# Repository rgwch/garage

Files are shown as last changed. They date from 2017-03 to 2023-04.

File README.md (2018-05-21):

# garage

Garagentoröffner per Raspberry Pi mit Relaisausgang und NodeJS-Express Server.
Der Server lässt sich per WebApp bedienen. Der Zustand des Tors (offen/zu) wird mit
einem Ultraschall-Sensor bestimmt. Wenn das Tor offen ist, wird ein weiterer Entfernungsmesser
eingeschaltet, der als Abstandswarner an der Stirnseite dient.

## Hardware

* Raspberry Pi Zero, B+, 2 oder 3.
* 2 Relais oder Optokoppler
* 2 HC-SR-04 oder HC-SR-05 Ultraschall-Sensoren
* 1 Arduino Nano
* 3 Leuchtdioden grün / gelb / rot für Abstandswarner
* 2 Widerstände 330 Ohm
* 1 Widerstand 470 Ohm
* 1 Netzteil für Raspberry Pi (Der Arduino wird über den Raspberry versorgt)

3D-Drucker für die Gehäuse.

## Software

NodeJS 10.x, z.B. so:

      sudo apt-get remove nodejs
      cd
      mkdir apps
      cd apps
      wget http://nodejs.org/dist/latest-v10.x/node-v10.1.0-linux-armv6l.tar.xz
      tar -xf node-v10.1.0-linux-armv6l.tar.xz
      mv node-v10.1.0-linux-armv6l node10
      sudo ln -s /home/pi/apps/node10/bin/node /usr/bin/node
      sudo ln -s /home/pi/apps/node10/bin/npm /usr/bin/npm
      echo export PATH=$PATH:/home/pi/apps/node10/bin >>../.profile

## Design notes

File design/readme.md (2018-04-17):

# Design Dateien

## *.scad

Dies sind Programme im OpenScad-Format, 
um die Gehäuse für den Raspberry, den Arduino und die Sensoren zu drucken.

Vorgehen, zum Beispiel für Ubuntu 17.04:

* `sudo apt-get install openscad slic3r`
* slic3r starten und Default-Einstellungen passend zum 3D-Drucker einstellen. (Vor allem Druckbett-Grösse, Filament-Durchmesser, Heizung)
* `./build_all.sh`
* gcode Dateien zum Drucker schicken.

### Dateien

* hc-sr04.scad / png: Gehäuse für den Ultraschallsensor des Garentor-Öffners
* klammer.scad / png: Klammer, um den Sensor an der Schiene des Tors zu befestigen
* nano_sono.scad / png: Gehäuse für Ultraschallsensor, Arduino und LEDs des Abstanswarner
* garage.fzz / png: Schema des Elektronik Aufbaus (Frtitzing Format)

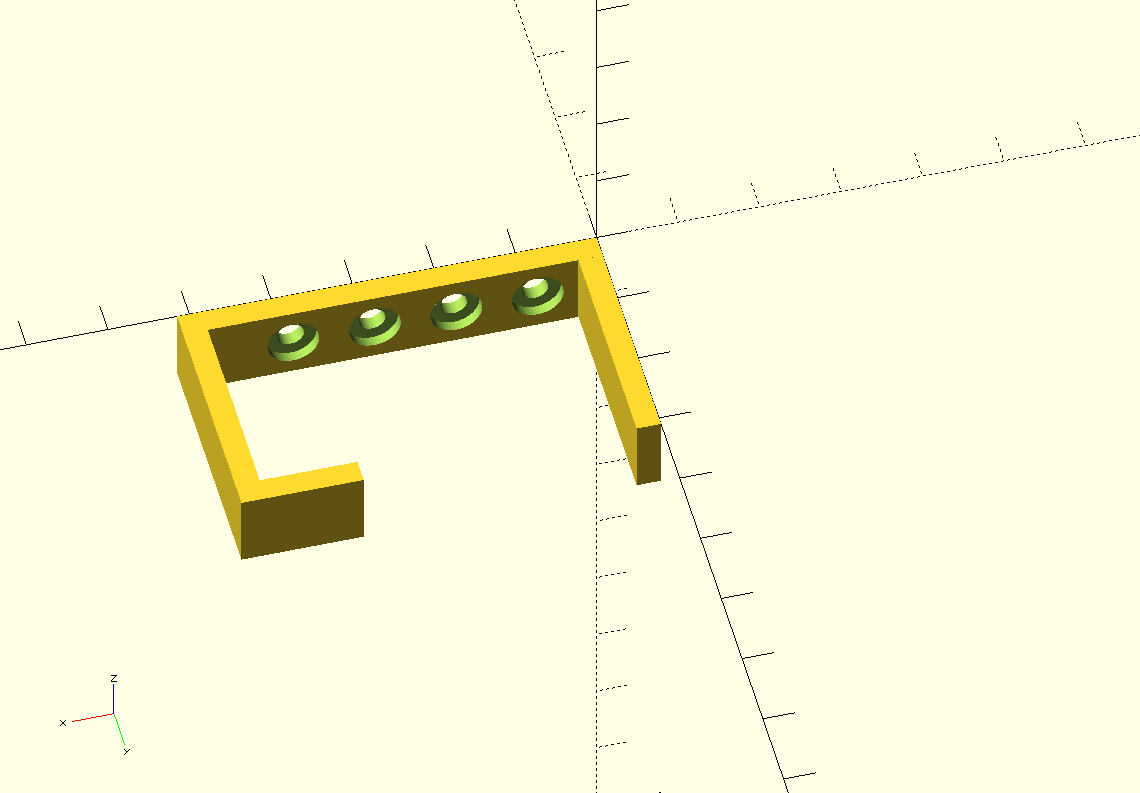
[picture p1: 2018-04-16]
design/klammer.png

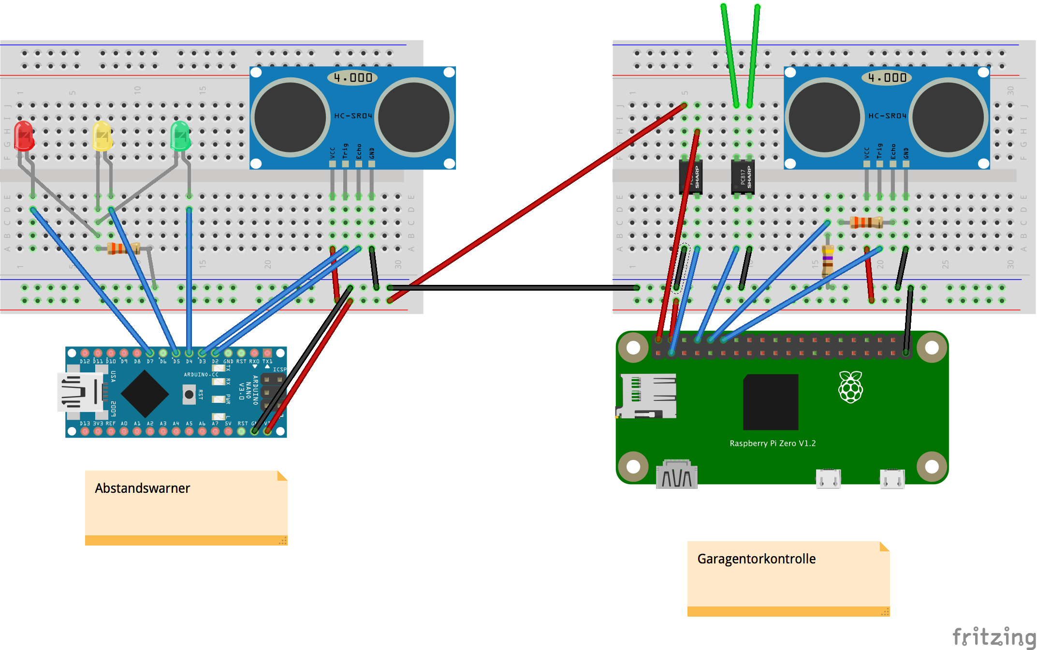
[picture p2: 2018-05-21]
design/garage_bb.png

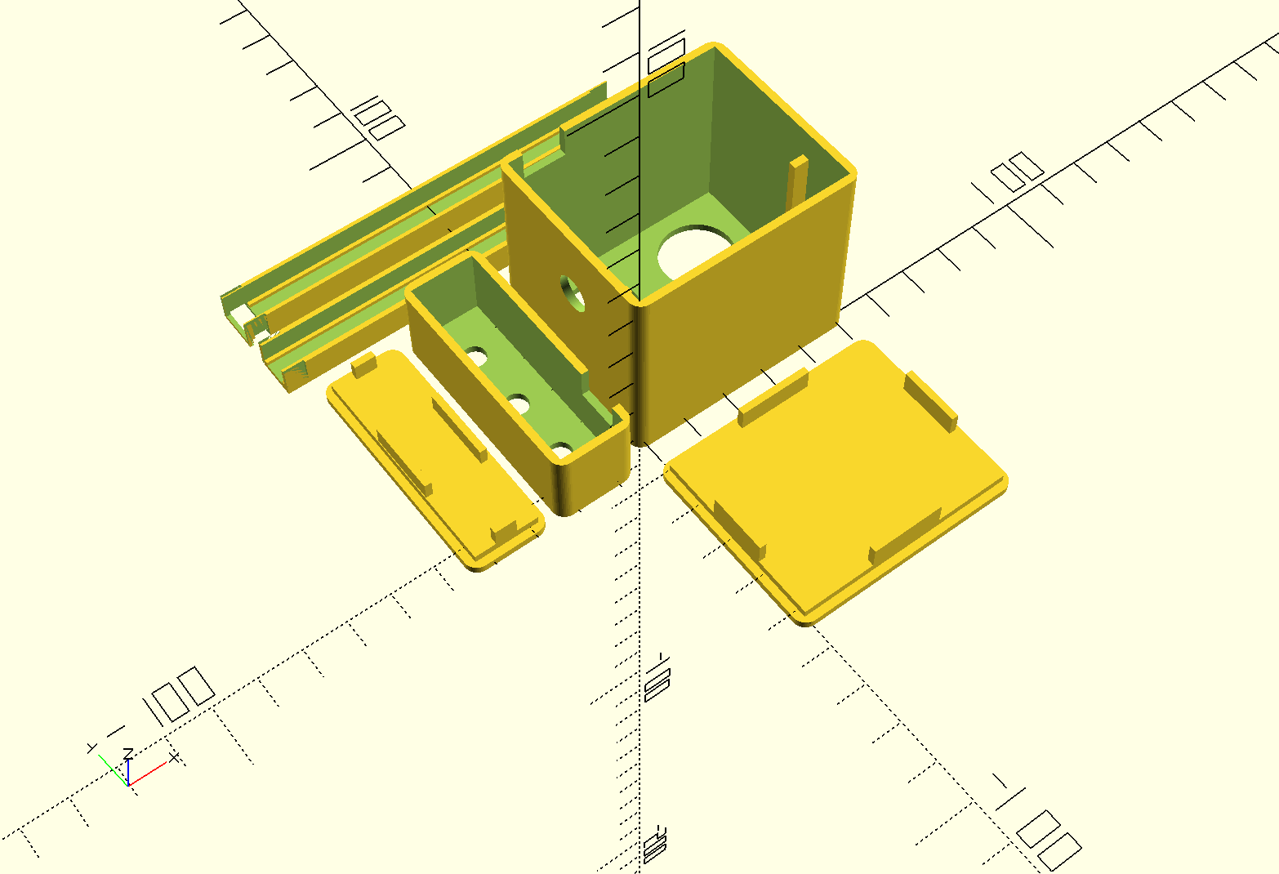
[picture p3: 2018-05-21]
design/nano_sono_v3.png

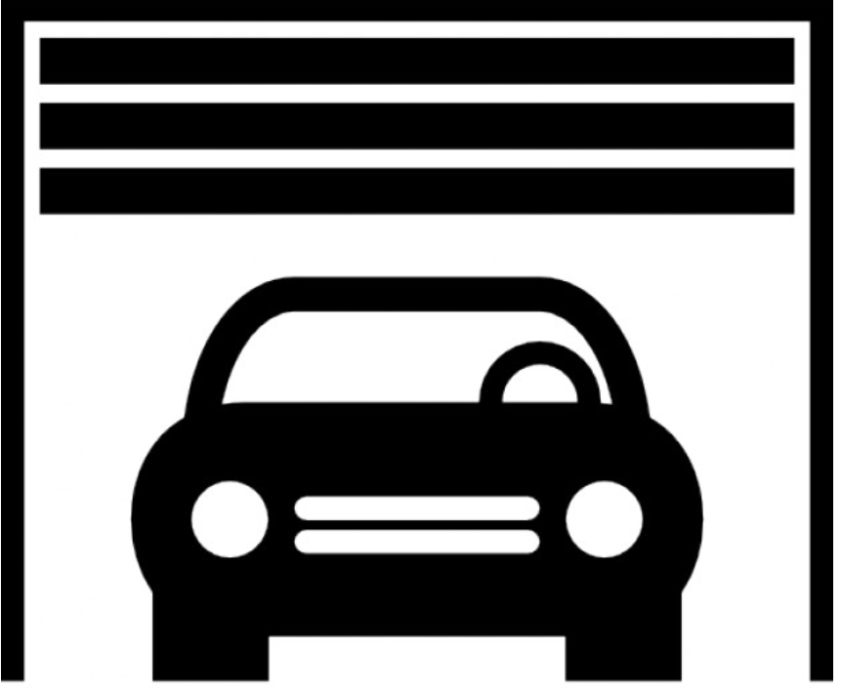
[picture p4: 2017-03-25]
public/garage.png

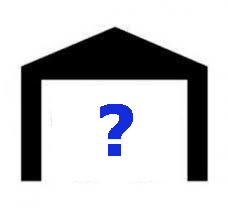
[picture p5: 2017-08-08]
public/garage_frage.png

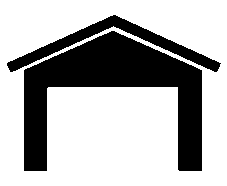
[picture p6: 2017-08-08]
public/garage_closing.gif

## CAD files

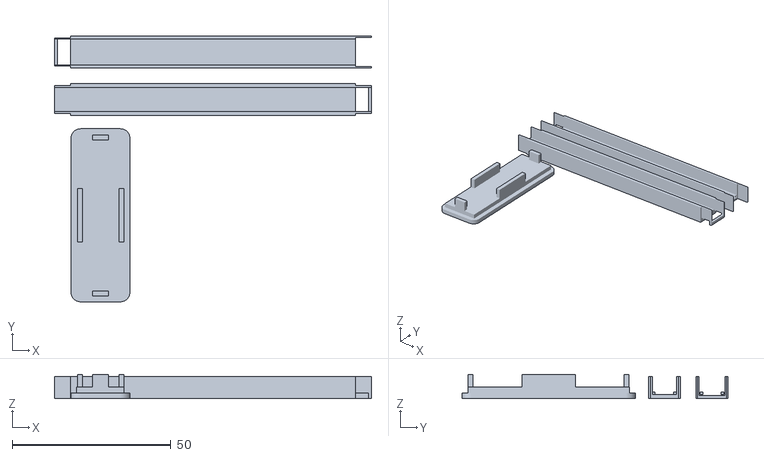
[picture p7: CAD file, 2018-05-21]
design/nano_sono_v3.stl
100.0 x 83.8 x 7.60

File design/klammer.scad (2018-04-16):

fit=0.2;
width=10;
thick=3;
inner_height=45.5;
inner_depth=25;
hook_size=12;
screw_head_diameter=6.0;
screw_head_thick=2.8;
screw_diameter=2.9;
screw_head_round=true;

height=inner_height+2*thick;
depth=inner_depth+2*thick;

front=[width,thick,inner_height];
top=[width,inner_depth,thick];
hook=[width,thick,hook_size];
fill=[width,thick,thick];

rotate([0,90,0]){
    union(){
        translate([0,0,thick]){
            difference(){
                cube(front);
                screw(5);
                screw(15);
                screw(25);
                screw(35);
            }
            translate([0,thick,inner_height]){
                cube(top);
                translate([0,top.y,-hook_size])
                    cube(hook);
            }
            translate([0,thick,-thick]){
                cube(top);
            }
        }

        translate([0,0,0]) cube(fill);
        translate([0,0,height-thick]) cube(fill);
        translate([0,depth-thick,0]) cube(fill);
        translate([0,depth-thick,height-thick]) cube(fill);
        
    }
}
module screw(pos){
    rotate([90,0,0]){
        translate([width/2,pos,-(1.5*thick)]){
            cylinder(r=screw_diameter/2+fit,h=thick*2,$fn=50);
            if(screw_head_round==false){
                cylinder(r=screw_head_diameter/2+fit,h=screw_head_thick,$fn=6);
            }else{
                cylinder(r=screw_head_diameter/2+fit,h=screw_head_thick,$fn=50);                 
            }
        }
    }
}

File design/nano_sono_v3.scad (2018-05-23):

/**********************************************************
    Gehäuse für einen HC-SR04 oder 05 Ultraschall Sensor, 
    einen Arduino Nano und 3 LEDs
    
    Schichtdicke: 0.3 mm, Filament PLA 1.75 mm
*********************************************************/
include <toolbox_1.1.scad>
use <devices.scad>

thick=1.8;              // Wanddicke. 
length=46;      // Platzbedarf für den HC-SR 04
width=21;
depth=17;
diameter=17;            // Durchmesser der Sender/Empfänger
offset=1.9;             // Abstand Sender/Empfänger von Wand
steps=100;              // Schritte für Kreisberechnung
platine_t=1.5;          // Masse der Platine mit dem Arduino
platine_w=38;
platine_l=48;
height=42;
clearance_floor=5;      // Abstand von der Unterseite für Verdrahtungen etc.
racksize=3.5;           // Grösse der Führungsschienen für die Platine
level_y=clearance_floor+thick+platine_t+racksize;
ledsize=5.35;            // Durchmesser der LEDs (inkl. Schrumpfkorrektur)
channel_width=10;
channel_depth=7;
channel_thick=1.2;      // Wandstärke Verbindungskanal

/*
    Die Box
*/

union(){
    difference(){
         roundedBox([platine_l,height,platine_w+5],3,thick);  
        translate([center(platine_l,length),height-diameter-3*offset,-offset])
            hcsr04();
        
        buchse(platine_w-15);
        translate([2*thick,height-5,platine_w])
           cube([10,10,7]);
    }

    rack([0,clearance_floor+thick,thick]);
    rack([platine_l-racksize,clearance_floor+thick+5,thick]); 
    translate([center(platine_l,10),19,0])
        cube([10,5,3]);
}


/*
    Der Deckel
*/


union(){
            translate([0,-(height+10),0]){
                roundedCover([platine_l,height,0],3,thick,latch_x=5,latch_y=5);
            }
     
}


/*
 Das abgesetzte Gehäuse für die LEDs
*/

union(){
   
    translate([-7,-4,0]){
      rotate([0,0,90])
        difference(){
            roundedBox([platine_l,15,15],3,thick);
            offs=3;    
            dist=(platine_l-2*offs)/3;    
            led(offs+dist/2);
            led(offs+dist+dist/2);
            led(offs+2*dist+dist/2);
            translate([2*thick,-5,10])
                cube([10,10,7]);
  
        }    
    }
}


/*
Deckel für LED Gehäuse
*/
translate([-28,-4,0]){
    rotate([0,0,90])
        roundedCover([platine_l,15,0],3,thick,latch_x=4,latch_y=4);
}

// Verbindungskanal 
translate([-50,platine_w+15,-thick]){
    union(){
    difference(){
            cube([100,channel_width,channel_depth]);
     
        translate([-5,channel_thick,channel_thick])
            cube([110,channel_width-2*channel_thick,channel_depth]);
        
        translate([95,0,0]) 
            cube([10,channel_thick/2,10]);
        translate([95,channel_width-channel_thick/2,0])
            cube([10,channel_thick/2,10]); 
        translate([95,-5,-2])
             cube([4,15,thick+2]);
        
        translate([0,0,0]) 
            cube([5,channel_thick/2,10]);
        translate([0,channel_width-channel_thick/2,0])
            cube([5,channel_thick/2,10]); 
     
        
    }
    translate([0,channel_thick,channel_thick]) cube([95,0.9,0.9]);
    translate([0,channel_width-0.9-channel_thick,channel_thick]) 
        cube([95,0.9,0.9]);
      
    }
}

translate([-50,platine_w+30,-thick]){
    union(){
     difference(){
        cube([100,channel_width,channel_depth]);
        translate([-5,channel_thick,channel_thick])
            cube([110,channel_width-2*channel_thick,channel_depth]);
         
        translate([95,channel_thick/2,0]) 
            cube([5,channel_thick/2,10]);
        translate([95,channel_width-channel_thick,0])
            cube([5,channel_thick/2,10]); 
         
        translate([95,channel_thick/2,-channel_thick])
            cube([5,channel_width-channel_thick,10]);
         cube([5,channel_thick/2,10]);
        translate([0,channel_width-channel_thick/2,0])
            cube([5,channel_thick/2,10]);
        translate([1,-5,-2])
          cube([4,15,thick+2]);
        
    }
    translate([5,channel_thick,channel_thick]) cube([90,0.9,0.9]);
    translate([5,channel_width-0.9-channel_thick,channel_thick]) 
        cube([90,0.9,0.9]);
    
    }
}


module led(x){
    translate([x,8,-thick-3])
        cylinder(r=ledsize/2,h=10,$fn=steps);           

}
    
module buchse(x){
    translate([-5,height/2.2,thick+4+x])
        rotate([0,90,0])
            cylinder(r=4.1,h=10,$fn=steps);
    
}

module rack(pos){
translate(pos) 
    cube([racksize,1.8,platine_w-thick]);

}

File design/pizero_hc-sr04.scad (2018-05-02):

/****************************************************************************************
    Gehöuse für einen Raspberry Pi Zero, einen HC-SR-04 oder HC-SR-05 Ultraschall-Sensor
    ein Relais und eine Steckbuchse.
    
    Material: PLA 1.75mm
    Schichtdicke: 0.3mm
    Infill: 20%
    Support: Nein
****************************************************************************************/
include  <toolbox_1.1.scad>

// Wanddicke global 
thick=1.2;

// Stufenzahl für runde Strukturen
steps=100;

// Raspberry-Teil
base_length=65.4;   // Länge der Platine
spare_length=3;     // Reserve Länge
base_width=30;      // Breite der Platine
spare_width=2;      // Reserve Breite
corner_radius=3;    // Rundungsradius (nur wenn roundedBox als Basis genommen wird)
hole_offset=3.5;    // Abstand der Löcher von den Kanten
raspi_height=15;    // Höhe für die Raspi Platine inkl. Anschlüsse
hc05_height=23;     // Höhe für den Ulztraschall-Sensor
total_height=raspi_height+hc05_height;
support_radius=3.5; // Radius der Stützscheiben
support_height=2;   // Dicker der Stptzscheiben, Bodenfreiheit für den Raspi
pillar_radius=2.5/2;    // Dicke der Löcher
pillar_height=4;    // Höhe der Führungsstifte für die RAspi-Halterung

// HC-SR-05 Teil
hc05_length=46; 
hc05_width=21;
hc05_depth=17;
hc05_diameter=17;
hc05_offset=1.9;
 
// Halterungen 
screw=3;            // Dicke der Schraube
fixation_size=8;   // Dicke der Halter
fixation_depth=8;
  


// Raspberry
union(){
    difference(){
        box(inner_size=[base_length+2*spare_length,base_width+2*spare_width,raspi_height+hc05_height],radius=corner_radius,thick=thick);
        
    // Stromanschluss    
    translate([spare_length+49.5,-5-thick,support_height+1])    
        cube([10,10,5]);  
    // Kühlschlitze im Boden    
    for(i=[10:5:45])  slot(i,base_width);  

    // Öffnungen für Ultraschall-Sensor
    rotate([90,0,0]){
        translate([
            hc05_diameter/2+hc05_offset,
            hc05_diameter/2+raspi_height+hc05_offset,
            -thick])
                cylinder(r=hc05_diameter/2,h=hc05_depth+5,$fn=steps);
        
        
        translate([hc05_length-hc05_diameter/2-hc05_offset,
               hc05_diameter/2+raspi_height+hc05_offset,
                -thick])
                cylinder(r=hc05_diameter/2,h=hc05_depth+5,$fn=steps);
        }
    // Öffnung für Steckbuchse
        rotate([90,0,90]){
            translate([base_width-23,raspi_height+10,base_length])
                cylinder(r=4.1,h=10,$fn=steps);
        
            }
        translate([base_length+spare_length,15,raspi_height+1.5])
               cube([10,17.2,14.3]);
    }
    
    
    // Stützen
    raspi_pillar(spare_length+hole_offset+0.3,spare_width+hole_offset);
    raspi_pillar(spare_length+base_length-hole_offset,spare_width+hole_offset);
    raspi_pillar(spare_length+hole_offset+0.3,base_width+spare_width-hole_offset);
    raspi_pillar(spare_length+base_length-hole_offset,base_width+spare_width-hole_offset);
    
    inlay_pillar(0,0);
    inlay_pillar(0,base_width+2*spare_width-2);
    inlay_pillar(base_length+2*spare_length-2,0);
    inlay_pillar(base_length+2*spare_length-2,base_width+2*spare_width-2);
    
    translate([-fixation_size,
        base_width+fixation_size/2+thick,
        -thick]) fixation();
    translate([base_length+2*spare_length,
        base_width+fixation_size/2+thick,
        -thick]) fixation();
}

// Zwischenboden
translate([0,-base_width-spare_width-4,-thick])
        inlay();

// Deckel
translate([0,base_width+spare_width+2*thick+3]){
    difference(){
        cover(inner_size=[base_length+2*spare_length,base_width+2*spare_width,raspi_height+     hc05_height], thick=thick, latch_y=5, latch_x=2);
     for(i=[4:5:54]) slot(i,base_width);   
        
   }
}


// Träger mit Führungsstift für den Raspi
module raspi_pillar(x,y){
    translate([x,y,0]){
        union(){
            cylinder(r=support_radius,h=support_height,$fn=steps);
            cylinder(r=pillar_radius,h=pillar_height,$fn=steps);
        }
    }
    
}

// Stütze für Zwischenboden
module inlay_pillar(x,y){
    translate([x,y,0]) 
        cube([2,2,raspi_height-2]);
}

// Zwischenboden
module inlay(){
    difference(){
        cube([base_length+2*spare_length-0.6,base_width+2*spare_width-0.3,1.5]);
      translate([5,2,-thick-4])
        cube([35,19,thick+10]);
      translate([5,24.5,thick-4])
        cube([base_length-5,12,thick+10]);
  
    }
    
}

// Halterung mit Öffnung für M3 Schraube
module fixation(x){
    difference(){
        rotate([90,0,0])
        roundedCube([fixation_size,fixation_depth,fixation_size],radius=3);
            rotate([90,0,0])
                translate([fixation_size/2,fixation_depth/2,-30])
                    cylinder(d=screw,h=50,$fn=steps);
    }
}

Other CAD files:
design/relay.scad
design/toolbox.scad
design/toolbox_1.1.scad

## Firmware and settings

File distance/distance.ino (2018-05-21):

/**
 * Sketch für Arduino:
 * Entfernung messen, und je nachdem eine rote, gelbe oder grüne LED einschalten
 */
 // Pins definieren
const int trigger = 5;
const int echo = 6;
const int red=7;
const int yellow=8;
const int green=9;

const int RED_DISTANCE=15; //cm
const int YELLOW_DISTANCE=50;

const long MAX_TIME = 20000;

void setup() {
  pinMode(trigger,OUTPUT);
  pinMode(echo,INPUT);
  pinMode(red,OUTPUT);
  pinMode(yellow,OUTPUT);
  pinMode(green,OUTPUT);
}

// Alle 500ms eine Messung machen und LEDs entsprechend schalten.
// Delays für Blinkeffekt
void loop() {
  digitalWrite(red,0);
  digitalWrite(yellow,0);
  digitalWrite(green,0);
  delay(250);
  int distance=ping();
  if(distance<RED_DISTANCE){
    digitalWrite(red,1);
  }else if(distance<YELLOW_DISTANCE){
    digitalWrite(yellow,1);
  }else{
    digitalWrite(green,1);
  }
  delay(250);
}

/*
  Der HC-SR04 startet eine Messung mit fallender Flanke auf trigger, auf dem vorher mindestens
  10us HIGH angelegt war. Er setzt dann echo zunächst auf HIGH und bei Empfang des Echos wieder auf LOW.

  Entfernung messen: trigger auf LOW, dann 15 us auf HIGH,
  dann wieder auf LOW, dann darauf warten, dass der Echo-Pin von HIGH auf LOW geht 
  und aus der dazwischen liegenden Zeit die 
  Entfernung berechnen (Schallgeschwindigkeit in Luft: 0.034cm/us).
*/
int ping() {
  digitalWrite(trigger,LOW);
  delay(2);
  digitalWrite(trigger, HIGH);
  delayMicroseconds(15);
  digitalWrite(trigger, LOW);
  long time = pulseIn(echo, HIGH);
  return (time/2)*0.034;
}

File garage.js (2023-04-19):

/**
 *  Garagentor-Fernbedienung mit Raspberry Pi
 *  (c) 2017-2018 by G. Weirich
 *
 * 8.4.2018: Verwende Ultraschall Sensor HC SR 04 zum feststellen, wo das Garagentor steht anstelle des
 * Mikroschalters. Damit wird das Problem behoben, dass die Anzeige unzuverlässig ist, weil das Garagentor
 * nicht immer exakt am selben Ort anhält (abhängig von Temperatur, Luftfeuchtigkeit, Gespenstern usw.)
 * Wir vereinfachen das: Wenn die Oberkante des Garagentors näher als MAX_DISTANCE vom Sensor ist,
 * betrachten wir es als offen.
 * 15.4.2018: Wechsel vom PiFace auf ein Standard-Relais, das mit onoff geschaltet wird.
 * Ausserdem neue Funktion: Abstandswarner an der Stirnseite der Garage einschalten, wenn das Tor offen ist.
 */

/* eslint-disable no-console*/
'use strict'

// Damit wir das Programm auf einem normalen PC ohne GPIO testen können. Wenn es auf dem echten Pi läuft, true setzen
const realpi = false
//const debug = false;

// Pin-Definitionen
const GPIO_GARAGE = 18 // Relais für Garagentorantrieb
const GPIO_ECHO = 15 // Echo vom HC-SR-04
const GPIO_TRIGGER = 14 // Trigger für den HC-SR-04

// Welcher Pin-Zustand den Aktor einschaltet. Hängt vom verwendeten Relais-Typ ab
const ON = 0
const OFF = 1

// Maximaldistanz, bis zu der das Garagentor als offen erkannt wird.
const MAX_DISTANCE = 100

// Dauer des simulierten Tastendrucks in Millisekunden
const time_to_push = 800
// Dauer des Öffnungs/Schliessvorgangs des Tors in ms
const time_to_run = 17000
// Aussperren bei falscher Passworteingabe in ms
const lock_time = 3000

const checkLightState = 'http://homepi.lan:8087/get/aussenlicht_manuell'
const setLightState = 'http://homepi.lan:8087/set/aussenlicht_manuell?value='

const fs = require('fs')
const ping = require('./measure')
const fetch = require('node-fetch')
const https = realpi ? require('https') : require('http')
const express = require('express')
const nconf = require('nconf')
const hash = require('crypto-js/sha256')
const path = require('path')
const bodyParser = require('body-parser')
const salt = "um Hackern mit 'rainbow tables' die Suppe zu versalzen"
const favicon = require('serve-favicon')

nconf.file(__dirname + '/users.json')
const app = express()
// Dieses Flag nutzen wir später, um den Server temporär inaktiv zu schalten.
let disabled = false
// Dieses Flag zeigt an, dass das Garagentor gerade fährt
let running = false
// Hier sammeln wir schiefgegangene Login-Versuche
const failures = {}

app.set('view-cache', true)
app.use(favicon(path.join(__dirname, 'public', 'favicon.ico')))
app.use(express.static(path.join(__dirname, 'public')))

/*
 HTTPS-Server erstellen, damit Usernamen und Passwörter verschlüsselt übermittelt werden.
 Als Zertifikat kann man entweder ein self-signed certificate verwenden
 (openssl req -x509 -newkey rsa:2048 -keyout key.pem -out cert.pem -days 365 -nodes).
 Dann muss man allerdings damit leben, dass der Browser eine "Sicherheitswarnung" ausgibt.

 Oder man erstellt ein Zertifikat via letsencrypt, mit "sudo certbot certonly --manual" und kopiert
 "privkey.pem" nach "key.pem" und "fullchain.pem" nach "cert.pem".
 Dann muss man allerdings, das Zertifikat alle drei Monate erneuern, weil Letsencrypt keine länger gültigen
 Zertifikate ausstellt.

 Oder man kauft irgendwo ein kostenpflichtiges Zertifikat. Aber das scheint mir für einen Garagentorantrieb
 eigentlich zu aufwändig.

 Wenn realpi==false ist, wird ein http-server ohne ssl gestartet.
 */

let src = __dirname
https
  .createServer(
    {
      key: realpi ? fs.readFileSync(src + '/key.pem') : '',
      cert: realpi ? fs.readFileSync(src + '/cert.pem') : '',
    },
    app,
  )
  .listen(2017)

// Auf einem echten Pi ist Gpio auf onoff (https://www.npmjs.com/package/onoff) gesetzt
// Auf einem anderen PC wird es einfach mit leeren Funktionen simuliert.

let relay
let hc_trigger
let hc_echo
let lightState

if (realpi) {
  const Gpio = require('onoff').Gpio

  relay = new Gpio(GPIO_GARAGE, 'high')
  hc_trigger = new Gpio(GPIO_TRIGGER, 'out')
  hc_echo = new Gpio(GPIO_ECHO, 'in')
} else {
  let Fake = require('./fakegpio')
  relay = new Fake(GPIO_GARAGE, 'out')
  hc_trigger = new Fake(GPIO_TRIGGER, 'out')
  hc_echo = new Fake(GPIO_ECHO, 'in')
}

relay.writeSync(OFF)

/**
 * Expressjs sagen, dass die Views im Verzeichnis "views" zu finden sind, und dass
 * pug (ex-Jade) benötigt wird, um sie nach HTML zu konvertieren.
 */
app.set('views', path.join(__dirname, 'views'))
app.set('view engine', 'pug')

/**
 * Expressjs mitteilen, dass wir json- und urlencoded Parameter im request body erwarten
 */
app.use(bodyParser.json())
app.use(
  bodyParser.urlencoded({
    extended: false,
  }),
)

/************************
 * Hilfsfunktionen
 *
 ************************/

/**
 * Password hashen
 * @param pwd Klartext-Passwort
 * @returns sha256 gehashtes mit salt modifiziertes Passwort
 */
function encode(pwd) {
  const encoded = JSON.stringify(hash(pwd + salt))
  return encoded
}

/**
 Check, ob der aktuelle Anwender gesperrt ist
 @returns {boolean} true, wenn er gesperrt ist
 */
function isLocked(lockinfo) {
  if (lockinfo) {
    let now = new Date().getTime()
    let locked_until = lockinfo.time + Math.pow(2, lockinfo.attempt) * lock_time
    if (now < locked_until) {
      return true
    }
  }
  return false
}

/**
 * Aktuellen User sperren. Wenn er schon gesperrt ist, Sperrzeit verlängern
 * @param user user
 * @returns {number} Zahl an Sekunden der aktuellen Sperrzeit
 */
function setLock(user) {
  let now = new Date().getTime()
  let lockinf = failures[user] ? failures[user] : { attempt: 0 }
  lockinf.attempt += 1
  lockinf.time = now
  failures[user] = lockinf
  return Math.round((Math.pow(2, lockinf.attempt) * lock_time) / 1000)
}

async function checkLight() {
  try {
    const light = await fetch(checkLightState)
    if (light.ok) {
      const state = await light.json()
      lightState = state.val
      return state.val
    } else {
      return 3
    }
  } catch (err) {
    console.log(err)
    return 0
  }
}

async function toggleLight() {
  try {
    if (lightState == undefined) {
      lightState = await checkLight()
    }
    const exec = lightState == 0 ? 1 : 0
    const result = await fetch(setLightState + exec.toString())
    if (result.ok) {
      return true
    } else {
      throw 'could not set light'
    }
  } catch (err) {
    console.log(err)
    return false
  }
}
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

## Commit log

2017-03-26 back button in confirm view
2018-04-17 rename design folder
    [garage.fzz, hc-sr04.scad, klammer.scad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]
2018-04-18 corrected cover
    [nano_sono.scad]
2018-04-21 pi zero case added
    [nano_sono.stl, pizero_hc-sr04.scad, toolbox_1.1.scad]
2018-04-22 some doc
    [pizero_hc-sr04.scad]
2018-04-26 relay case
    [pizero_hc-sr04.scad, relay.scad, toolbox_1.1.scad]
2018-04-27 spare space
    [relay.scad, toolbox_1.1.scad]
2018-05-02 relays working
2018-05-20 added arduino distance measure
2018-05-21 pins arduino
2018-05-21 final(?) design changes
    [garage.fzz, nano_sono.scad, nano_sono_v3.scad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]
2018-05-21 distance sensor
2018-05-21 arduino manual
2018-05-23 umstellung auf state-konzept
    [hc-sr04.scad]
2021-12-11 remove material design files
